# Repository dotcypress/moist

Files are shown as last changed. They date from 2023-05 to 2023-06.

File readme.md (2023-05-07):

# moist

🌻 Soil Moisture Sensor

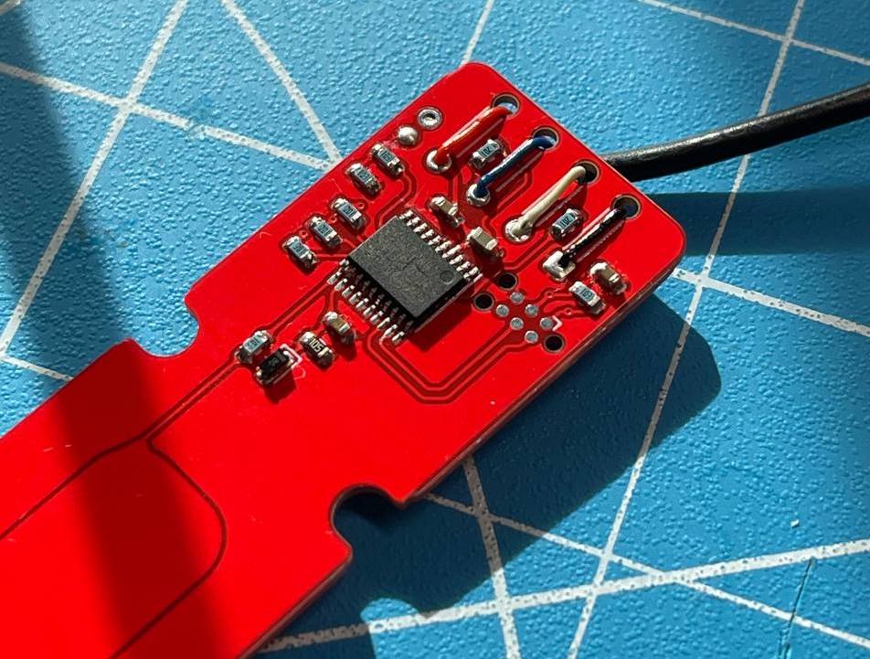
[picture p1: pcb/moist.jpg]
Soil Moisture Sensor


# Resources

* [Schematics](https://kicanvas.org/?github=https://github.com/dotcypress/moist/blob/main/pcb/moist.kicad_sch)
* [PCB](https://kicanvas.org/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)
* [BOM](https://htmlpreview.github.io/?https://github.com/dotcypress/moist/blob/main/pcb/bom/ibom.html)

## License

Licensed under either of

- Apache License, Version 2.0 ([LICENSE-APACHE](LICENSE-APACHE) or
  http://www.apache.org/licenses/LICENSE-2.0)
- MIT license ([LICENSE-MIT](LICENSE-MIT) or http://opensource.org/licenses/MIT)

at your option.

### Contribution

Unless you explicitly state otherwise, any contribution intentionally submitted
for inclusion in the work by you, as defined in the Apache-2.0 license, shall be
dual licensed as above, without any additional terms or conditions.

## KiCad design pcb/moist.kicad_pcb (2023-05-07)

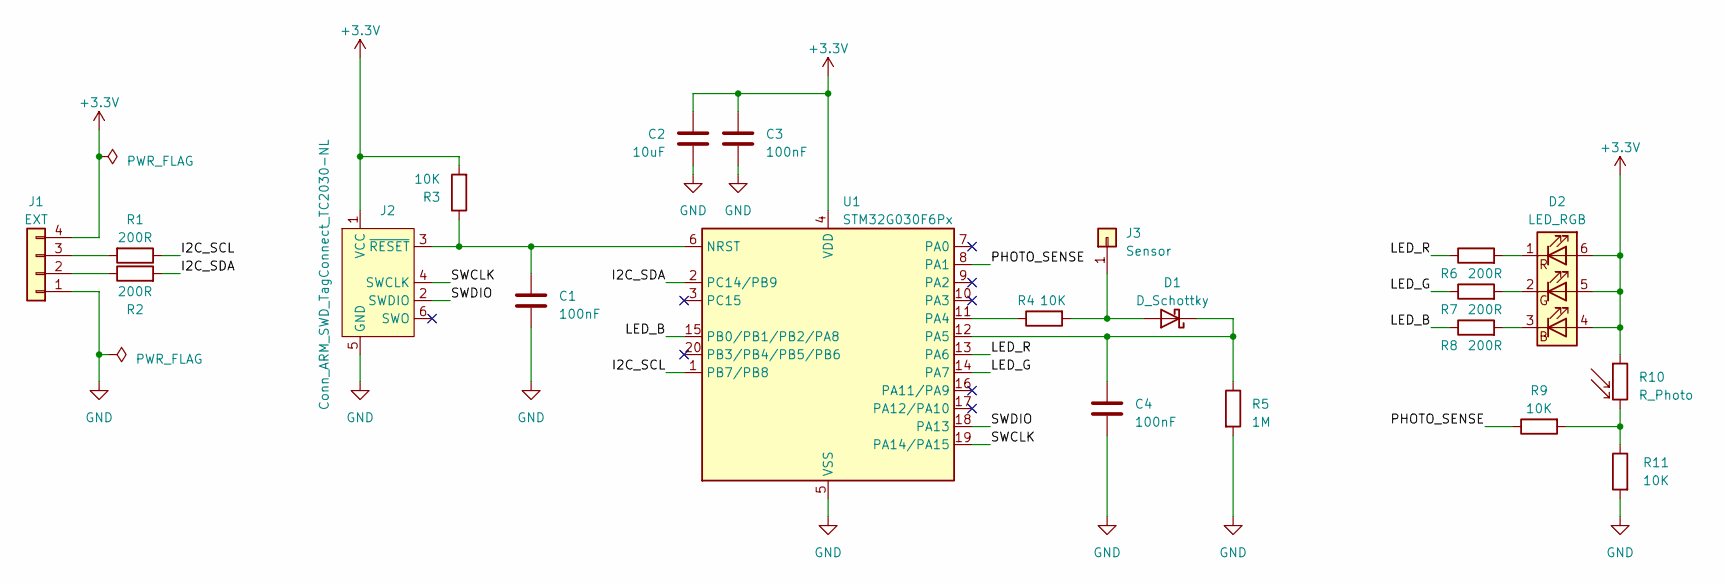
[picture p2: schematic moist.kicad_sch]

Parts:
C1, C3, C4: 100nF; C_0603_1608Metric
C2: 10uF; C_0603_1608Metric
D1: D_Schottky; D_0603_1608Metric
D2: LED_RGB; LED_RGB_PLCC-6
J1: EXT; SolderWire-0.1sqmm_1x04_P3.6mm_D0.4mm_OD1mm_Relief
J2: Conn_ARM_SWD_TagConnect_TC2030-NL; Tag-Connect_TC2030-IDC-NL_2x03_P1.27mm_Vertical
J3: Sensor; SensorPad
R1, R2, R6, R7, R8: 200R; R_0603_1608Metric
R3, R4, R9, R11: 10K; R_0603_1608Metric
R5: 1M; R_0603_1608Metric
R10: R_Photo; R_Axial_DIN0204_L3.6mm_D1.6mm_P1.90mm_Vertical
U1: STM32G030F6Px; TSSOP-20_4.4x6.5mm_P0.65mm

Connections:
+3.3V: C2.1, C3.1, D2.4 (BA), D2.5 (GA), D2.6 (RA), J1.4, J2.1 (VCC), R3.2, R10.1, U1.4 (VDD)
/I2C_SCL: R1.1, U1.1 (PB7/PB8)
/I2C_SDA: R2.2, U1.2 (PC14/PB9)
/LED_B: R8.1, U1.15 (PB0/PB1/PB2/PA8)
/LED_G: R7.1, U1.14 (PA7)
/LED_R: R6.1, U1.13 (PA6)
/PHOTO_SENSE: R9.1, U1.8 (PA1)
/SWCLK: J2.4 (SWCLK), U1.19 (PA14/PA15)
/SWDIO: J2.2 (SWDIO), U1.18 (PA13)
GND: C1.2, C2.2, C3.2, C4.2, J1.1, J2.5 (GND), R5.2, R11.2, U1.5 (VSS)
unnamed: D1.2 (A), J3.1, R4.2
unnamed: C4.1, D1.1 (K), R5.1, U1.12 (PA5)
unnamed: D2.3 (BK), R8.2
unnamed: D2.2 (GK), R7.2
unnamed: D2.1 (RK), R6.2
unnamed: J1.2, R2.1
unnamed: J1.3, R1.2
unnamed: C1.1, J2.3 (~RESET), R3.1, U1.6 (NRST)
unnamed: R9.2, R10.2, R11.1
unnamed: R4.1, U1.11 (PA4)

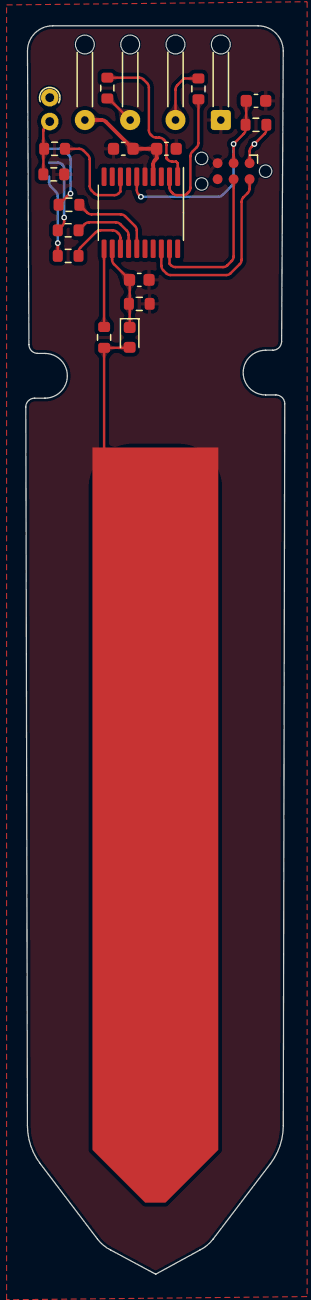
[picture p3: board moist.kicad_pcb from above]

Board: 2 copper layers, 20.6 x 99.2 mm, 21 parts (1 on the bottom side), 20 nets.

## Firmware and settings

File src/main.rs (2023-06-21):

#![no_std]
#![no_main]

extern crate panic_halt;
extern crate rtic;
extern crate stm32g0xx_hal as hal;

mod app;
mod config;
mod server;

use defmt_rtt as _;

use app::*;
use config::*;
use hal::analog::adc;
use hal::flash::{self, WriteErase};
use hal::gpio::*;
use hal::i2c;
use hal::pac::FLASH;
use hal::prelude::*;
use hal::stm32;
use hal::timer::pwm::PwmPin;
use hal::timer::*;

pub const ADDRESS: Address = 0x22;

pub type I2cClk = PB8<Output<OpenDrain>>;
pub type I2cSda = PB9<Output<OpenDrain>>;
pub type I2cDev = i2c::I2c<stm32::I2C1, I2cSda, I2cClk>;
pub type Sense = (adc::Adc, PA5<Analog>, PA1<Analog>);
pub type Led = (
    PwmPin<stm32::TIM3, Channel3>,
    PwmPin<stm32::TIM3, Channel2>,
    PwmPin<stm32::TIM3, Channel1>,
);

#[rtic::app(device = hal::stm32, peripherals = true, dispatchers = [CEC, PVD])]
mod moist {
    use super::*;

    #[shared]
    struct Shared {
        app: App,
    }

    #[local]
    struct Local {
        sense: Sense,
        i2c: I2cDev,
        led: Led,
        timer: Timer<stm32::TIM16>,
        flash: Option<stm32::FLASH>,
    }

    #[init]
    fn init(ctx: init::Context) -> (Shared, Local, init::Monotonics) {
        defmt::info!("init");

        let flash = Some(ctx.device.FLASH);
        let mut rcc = ctx.device.RCC.constrain();

        let port_a = ctx.device.GPIOA.split(&mut rcc);
        let port_b = ctx.device.GPIOB.split(&mut rcc);

        let mut i2c_cfg = i2c::Config::new(400.kHz());
        i2c_cfg.slave_address(ADDRESS);

        let mut i2c = ctx.device.I2C1.i2c(
            port_b.pb9.into_open_drain_output(),
            port_b.pb8.into_open_drain_output(),
            i2c_cfg,
            &mut rcc,
        );
        i2c.listen(i2c::Event::AddressMatch);

        let moisture_sense = port_a.pa5;
        let photo_sense = port_a.pa1;
        let mut adc = ctx.device.ADC.constrain(&mut rcc);
        adc.set_sample_time(adc::SampleTime::T_160);
        adc.set_precision(adc::Precision::B_12);
        adc.set_oversampling_ratio(adc::OversamplingRatio::X_16);
        adc.set_oversampling_shift(16);
        adc.oversampling_enable(true);

        let pwm = ctx.device.TIM14.pwm(200.kHz(), &mut rcc);
        let mut pwm = pwm.bind_pin(port_a.pa4);
        pwm.set_duty(pwm.get_max_duty() / 8);
        pwm.enable();

        let cfg = Config::load();
        let app = App::new(cfg);

        let mut timer = ctx.device.TIM16.timer(&mut rcc);
        timer.start(100.millis());
        timer.listen();

        let led_pwm = ctx.device.TIM3.pwm(1.kHz(), &mut rcc);
        let mut pwm_r = led_pwm.bind_pin(port_b.pb0);
        let mut pwm_g = led_pwm.bind_pin(port_a.pa7);
        let mut pwm_b = led_pwm.bind_pin(port_a.pa6);
        let duty = pwm_r.get_max_duty() + 1;
        pwm_r.set_duty(duty);
        pwm_g.set_duty(duty);
        pwm_b.set_duty(duty);
        pwm_r.enable();
        pwm_g.enable();
        pwm_b.enable();

        let led = (pwm_r, pwm_g, pwm_b);

        defmt::info!("init completed");
        (
            Shared { app },
            Local {
                i2c,
                timer,
                led,
                flash,
                sense: (adc, moisture_sense, photo_sense),
            },
            init::Monotonics(),
        )
    }

    #[task(binds = TIM16, local = [timer, sense], shared = [app])]
    fn timer_tick(ctx: timer_tick::Context) {
        let timer_tick::LocalResources { timer, sense } = ctx.local;
        let mut app = ctx.shared.app;
        let moisture = u16::MAX - sense.0.read(&mut sense.1).unwrap_or(0);
        let illuminance = sense.0.read(&mut sense.2).unwrap_or(0);
        app.lock(|app| app.push_samples(moisture, illuminance));

        timer.clear_irq();
    }

    #[task(priority = 2, binds = I2C1, local = [i2c], shared=[app])]
    fn i2c_rx(ctx: i2c_rx::Context) {
        let mut app = ctx.shared.app;
        match app.lock(|app| app.poll(ctx.local.i2c)) {
            Ok(Some(AppRequest::SetLedColor(color))) => {
                update_led::spawn(color).ok();
            }
            Ok(Some(AppRequest::SaveConfig(cfg))) => {
                save_nvm::spawn(cfg).ok();
            }
            Err(err) => {
                match err {
                    i2c::Error::Overrun => defmt::error!("Overrun"),
                    i2c::Error::Nack => defmt::error!("Nack"),
                    i2c::Error::PECError => defmt::error!("PEC Fault"),
                    i2c::Error::BusError => defmt::error!("Bus Fault"),
                    i2c::Error::ArbitrationLost => defmt::error!("Arbitration lost"),
                    i2c::Error::IncorrectFrameSize(s) => {
                        defmt::error!("Incorrect frame size: {}", s)
                    }
                };
            }
            _ => (),
        }
    }

    #[task(priority = 2, local = [led])]
    fn update_led(ctx: update_led::Context, color: [u8; 3]) {
        let max = ctx.local.led.0.get_max_duty() as u32 + 1;
        ctx.local.led.0.set_duty(max - color[0] as u32 * 256);
        ctx.local.led.1.set_duty(max - color[1] as u32 * 256);
        ctx.local.led.2.set_duty(max - color[2] as u32 * 256);
    }

    #[task(priority = 3, local = [flash])]
    fn save_nvm(ctx: save_nvm::Context, cfg: Config) {
        if let Some(flash) = ctx.local.flash.take() {
            *ctx.local.flash = Some(cfg.save(flash));
        }
    }

    #[idle]
    fn idle(_: idle::Context) -> ! {
        loop {
            rtic::export::nop();
        }
    }
}

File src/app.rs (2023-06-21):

use crate::config::*;
use crate::server::command;

pub type Address = u8;

pub enum BusEvent {
    Rx(Address),
    Tx(Address),
}

pub trait I2CPeripheral {
    type Error;

    fn poll(&mut self) -> Result<Option<BusEvent>, Self::Error>;

    fn rx(&mut self, bytes: &mut [u8]) -> Result<(), Self::Error>;

    fn tx(&mut self, bytes: &[u8]) -> Result<(), Self::Error>;

    fn flush(&mut self) -> Result<(), Self::Error>;
}

pub struct SensorState {
    raw: u16,
    cfg: SensorConfig,
}

impl SensorState {
    pub fn new(cfg: SensorConfig) -> Self {
        Self { cfg, raw: 0 }
    }

    pub fn val(&self) -> u16 {
        let val = self.raw.saturating_sub(self.cfg.offset) as u32 * 1024 / self.cfg.slope as u32;
        val.min(u16::MAX as _) as _
    }

    pub fn raw(&self) -> u16 {
        self.raw
    }

    pub fn update(&mut self, val: u16) {
        self.raw = val;
    }
}

pub enum AppRequest {
    SetLedColor([u8; 3]),
    SaveConfig(Config),
}

pub struct App {
    moisture: SensorState,
    illuminance: SensorState,
    led_color: u16,
    write_pend: Option<u8>,
    scratch: [u8; 2],
}

impl App {
    pub fn new(cfg: Config) -> Self {
        Self {
            moisture: SensorState::new(cfg.moisture),
            illuminance: SensorState::new(cfg.illuminance),
            led_color: 0,
            write_pend: None,
            scratch: [0; 2],
        }
    }

    pub fn push_samples(&mut self, moisture: u16, illuminance: u16) {
        self.moisture.update(moisture);
        self.illuminance.update(illuminance);
    }

    pub fn poll<E>(
        &mut self,
        i2c: &mut dyn I2CPeripheral<Error = E>,
    ) -> Result<Option<AppRequest>, E> {
        loop {
            match i2c.poll()? {
                None => {
                    i2c.flush()?;
                    break Ok(None);
                }
                Some(BusEvent::Tx(_)) => {
                    i2c.tx(&self.scratch)?;
                }
                Some(BusEvent::Rx(_)) => {
                    if let Some(cmd) = self.write_pend {
                        self.write_pend = None;

                        let mut inbox = [0; 2];
                        i2c.rx(&mut inbox)?;
                        let val = u16::from_be_bytes(inbox);

                        match cmd {
                            command::WRITE_MOISTURE_OFFSET => self.moisture.cfg.offset = val,
                            command::WRITE_MOISTURE_SLOPE => self.moisture.cfg.slope = val,
                            command::WRITE_ILLUMINANCE_OFFSET => self.illuminance.cfg.offset = val,
                            command::WRITE_ILLUMINANCE_SLOPE => self.illuminance.cfg.slope = val,
                            command::WRITE_LED => {
                                self.led_color = val;
                                let rgb = [
                                    self.led_color as u8 & 0x0f,
                                    (self.led_color >> 4) as u8 & 0x0f,
                                    (self.led_color >> 8) as u8 & 0x0f,
                                ];
                                break Ok(Some(AppRequest::SetLedColor(rgb)));
                            }
                            _ => unreachable!(),
                        }
                    } else {
                        let mut inbox = [0; 1];
                        i2c.rx(&mut inbox)?;
                        let cmd = inbox[0];

                        self.scratch = match cmd {
                            command::WRITE_MOISTURE_OFFSET
                            | command::WRITE_MOISTURE_SLOPE
                            | command::WRITE_ILLUMINANCE_OFFSET
                            | command::WRITE_ILLUMINANCE_SLOPE
                            | command::WRITE_LED => {
                                self.write_pend = Some(cmd);
                                continue;
                            }
                            command::READ_MOISTURE => self.moisture.val().to_be_bytes(),
                            command::READ_MOISTURE_RAW => self.moisture.raw().to_be_bytes(),
                            command::READ_MOISTURE_OFFSET => self.moisture.cfg.offset.to_be_bytes(),
                            command::READ_MOISTURE_SLOPE => self.moisture.cfg.slope.to_be_bytes(),
                            command::READ_ILLUMINANCE => self.illuminance.val().to_be_bytes(),
                            command::READ_ILLUMINANCE_RAW => self.illuminance.raw().to_be_bytes(),
                            command::READ_ILLUMINANCE_OFFSET => {
                                self.illuminance.cfg.offset.to_be_bytes()
                            }
                            command::READ_ILLUMINANCE_SLOPE => {
                                self.illuminance.cfg.slope.to_be_bytes()
                            }
                            command::READ_LED => self.led_color.to_be_bytes(),
                            command::SAVE_NVM => {
                                let cfg = Config::new(self.moisture.cfg, self.illuminance.cfg);
                                break Ok(Some(AppRequest::SaveConfig(cfg)));
                            }
                            _ => self.moisture.val().to_be_bytes(),
                        }
                    }
                }
            }
        }
    }

    pub fn moisture(&mut self) -> &mut SensorState {
        &mut self.moisture
    }

    pub fn illuminance(&mut self) -> &mut SensorState {
        &mut self.illuminance
    }
}

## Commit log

2023-05-07 rev 0x01
    [moist.kicad_pcb, moist.kicad_sch]
2023-06-21 led registers
